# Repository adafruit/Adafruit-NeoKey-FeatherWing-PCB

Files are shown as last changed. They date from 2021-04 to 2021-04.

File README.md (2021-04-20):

## Adafruit NeoKey FeatherWing PCB

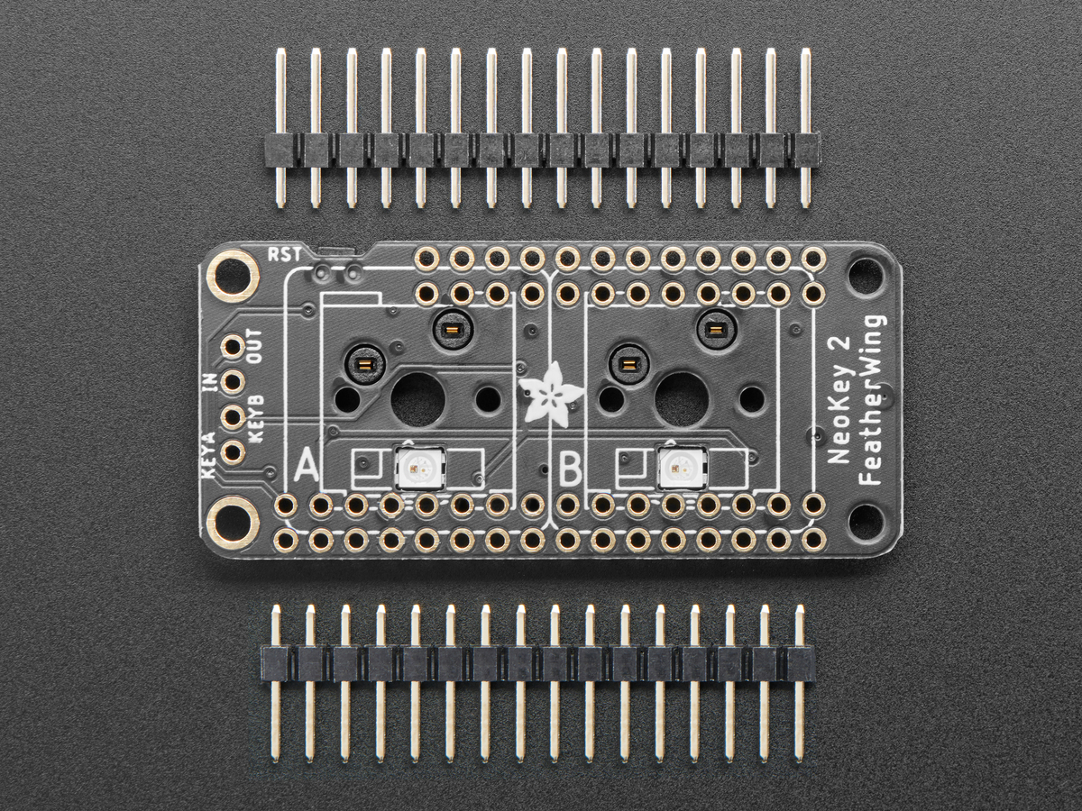
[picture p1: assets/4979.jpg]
<a href="http://www.adafruit.com/products/4979"><br/>
Click here to purchase one from the Adafruit shop</a>

PCB files for the Adafruit NeoKey FeatherWing. 

Format is EagleCAD schematic and board layout
* https://www.adafruit.com/product/4979

### Description

The only thing better than a nice mechanical key, is two of them, and ones that also can glow any color of the rainbow - and that's what the Adafruit NeoKey FeatherWing will let you do! This Wing plugs into any/all Feather main boards and can fit two Cherry MX or compatible switches to turn your Feather into the lil'est macro keypad.

Each Wing has two Kailh sockets, which means you can plug in any MX-compatible switches instead of soldering them in. You may need a little glue to keep the switches in place: hot glue or a dot of epoxy worked fine for us.

Beneath each switch is a reverse-mount NeoPixel pointing up through the spot where many switches would have an LED to shine though. The two pixels are chained together so you can control them as one 2-pixel NeoPixel strand.

We wired the switches up very simply, so you can use with any Feather. There's jumper pads you can cut to re-wire the switches and LED strand.

* Switch A - Connects to the Feather pin to the left of SCL, on most Feathers this is pin D5
* Switch B - Connects to the Feather pin two pins to the left of SCL, on most Feathers this is pin D6
* NeoPixel Input - Connects to the Feather pin three pins to the left of SCL, on most Feathers this is pin D9
* Bonus STEMMA QT connector allows you to make solderless connections between your Wing and a wide range of other sensors and accessories using a compatible cable. QT Cable is not included, but we have a variety in the shop.

Please note, each order comes with one assembled FeatherWing PCB and a two sticks of break-off header. Soldering is required to attach the header and connect to a Feather. Two mechanical switches and key caps are not included! Use any MX-compatible switch: Kailh, Gateron, etc all work.
### License

Adafruit invests time and resources providing this open source design, please support Adafruit and open-source hardware by purchasing products from [Adafruit](https://www.adafruit.com)!

Designed by Limor Fried/Ladyada for Adafruit Industries.

Creative Commons Attribution/Share-Alike, all text above must be included in any redistribution. 
See license.txt for additional details.

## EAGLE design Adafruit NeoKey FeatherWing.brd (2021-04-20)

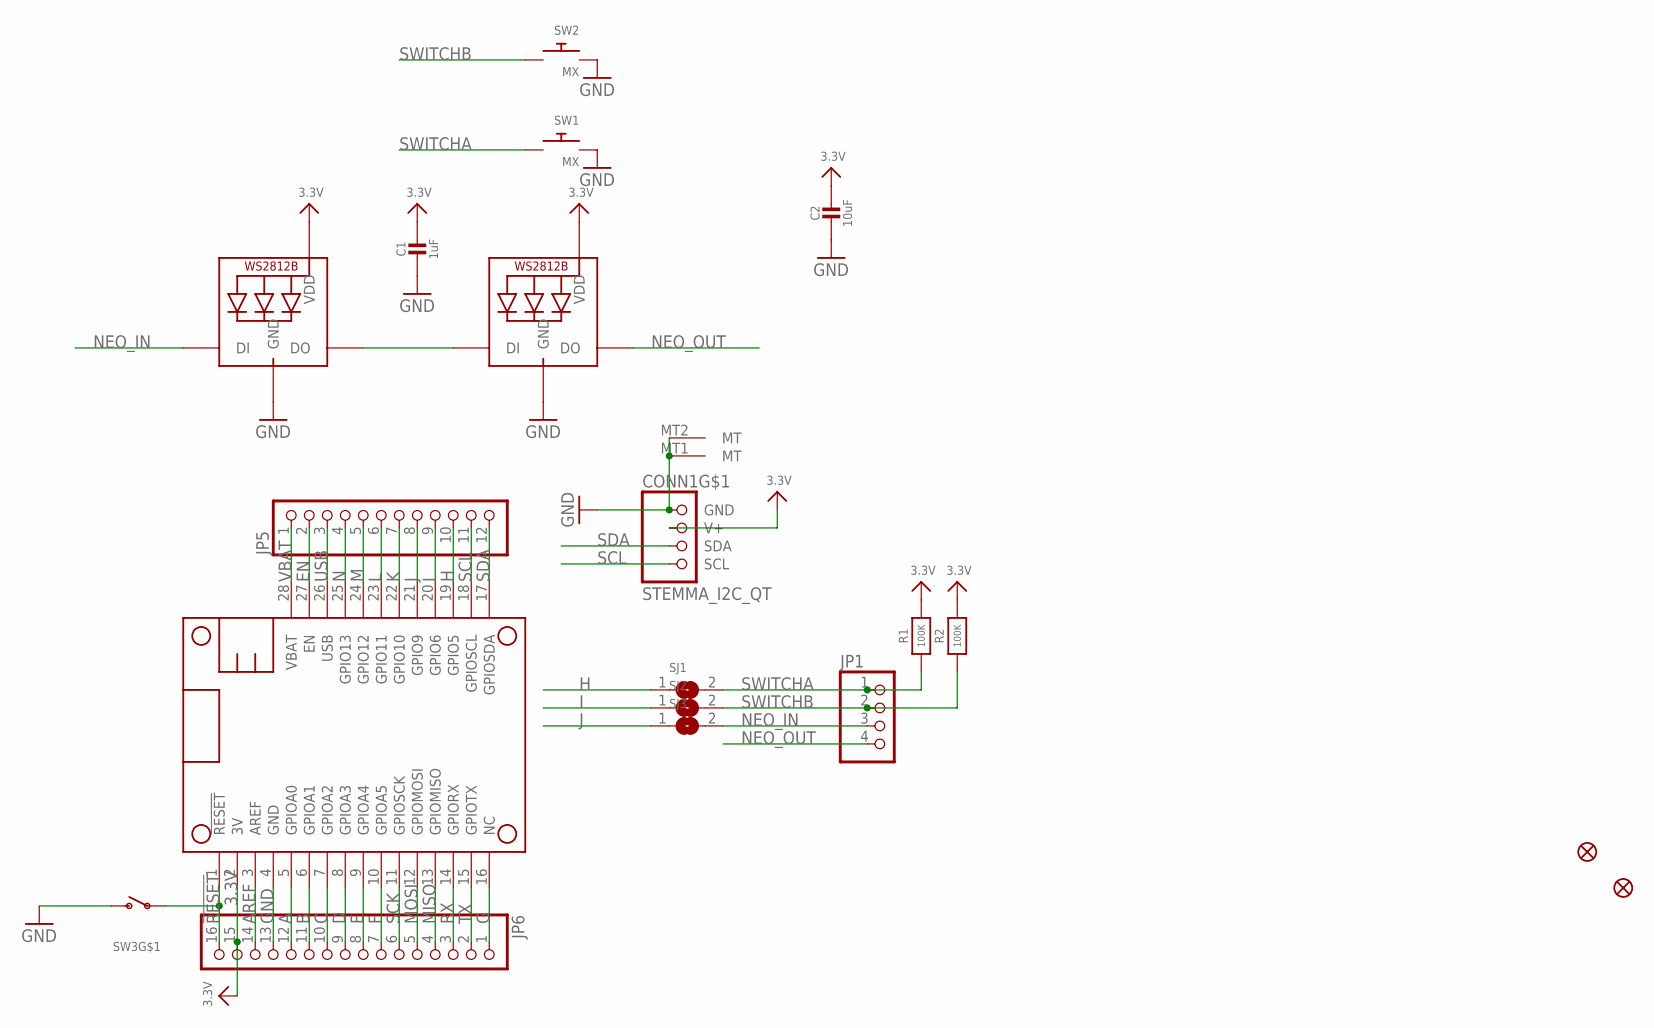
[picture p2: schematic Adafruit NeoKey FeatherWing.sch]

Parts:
C1: 1uF; 0603-NO
C2: 10uF; 0805-NO
CONN1: STEMMA_I2C_QT; JST_SH4
FID1, FID2: FIDUCIAL_1MM
JP1: HEADER-1X4ROUND; 1X04_ROUND
JP5: HEADER-1X12; 1X12_ROUND
JP6: HEADER-1X16ROUND; 1X16_ROUND
LED1, LED2: WS2812B_SK6812E; NEO3535_REVERSE
MS1: FEATHERWING_NODIM
R1, R2: 100K; 0603-NO
SJ1, SJ2, SJ3: SOLDERJUMPERCLOSED; SOLDERJUMPER_CLOSEDWIRE
SW1, SW2: MX; KAILH_SOCKET
SW3: SWITCH_SPST_TACT_RA; SPST_TACTILE_RA

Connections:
3.3V: C1.1, C2.1, CONN1.2 (V+), JP6.15, LED1.1-VDD (VDD), LED2.1-VDD (VDD), MS1.2 (3V), R1.2, R2.2
!RESET: JP6.16, MS1.1 (!RESET), SW3.1
A: JP6.12, MS1.5 (GPIOA0)
AREF: JP6.14, MS1.3 (AREF)
B: JP6.11, MS1.6 (GPIOA1)
C: JP6.10, MS1.7 (GPIOA2)
D: JP6.9, MS1.8 (GPIOA3)
E: JP6.8, MS1.9 (GPIOA4)
EN: JP5.2, MS1.27 (EN)
F: JP6.7, MS1.10 (GPIOA5)
G: JP6.1, MS1.16 (NC)
GND: C1.2, C2.2, CONN1.1 (GND), CONN1.MT1 (MT), CONN1.MT2 (MT), JP6.13, LED1.3-GND (GND), LED2.3-GND (GND), MS1.4 (GND), SW1.1, SW2.1, SW3.2 (S)
H: JP5.10, MS1.19 (GPIO5), SJ1.1
I: JP5.9, MS1.20 (GPIO6), SJ2.1
J: JP5.8, MS1.21 (GPIO9), SJ3.1
K: JP5.7, MS1.22 (GPIO10)
L: JP5.6, MS1.23 (GPIO11)
M: JP5.5, MS1.24 (GPIO12)
MISO: JP6.4, MS1.13 (GPIOMISO)
MOSI: JP6.5, MS1.12 (GPIOMOSI)
N: JP5.4, MS1.25 (GPIO13)
unnamed: LED1.4-DIN (DI), LED2.2-DOUT (DO)
NEO_IN: JP1.3, LED2.4-DIN (DI), SJ3.2
NEO_OUT: JP1.4, LED1.2-DOUT (DO)
RX: JP6.3, MS1.14 (GPIORX)
SCK: JP6.6, MS1.11 (GPIOSCK)
SCL: CONN1.4 (SCL), JP5.11, MS1.18 (GPIOSCL)
SDA: CONN1.3 (SDA), JP5.12, MS1.17 (GPIOSDA)
SWITCHA: JP1.1, R1.1, SJ1.2, SW1.2
SWITCHB: JP1.2, R2.1, SJ2.2, SW2.2
TX: JP6.2, MS1.15 (GPIOTX)
USB: JP5.3, MS1.26 (USB)
VBAT: JP5.1, MS1.28 (VBAT)

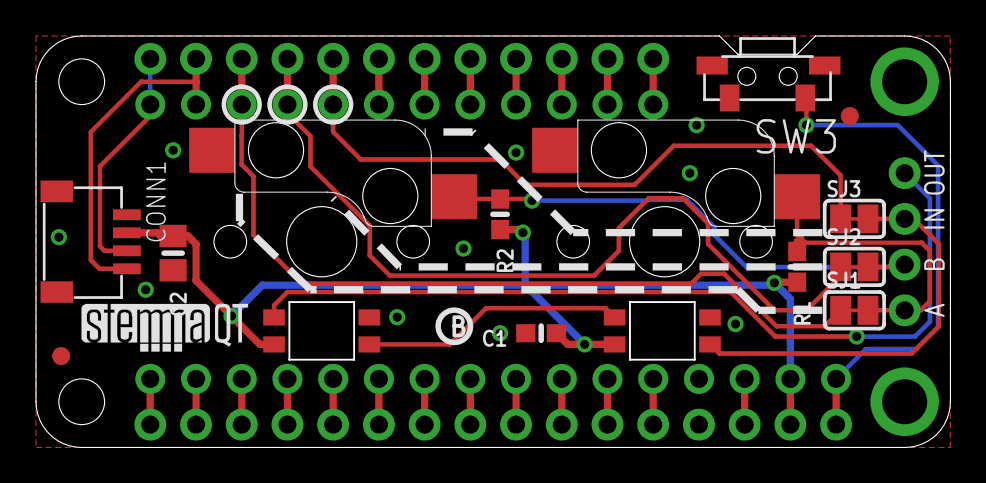
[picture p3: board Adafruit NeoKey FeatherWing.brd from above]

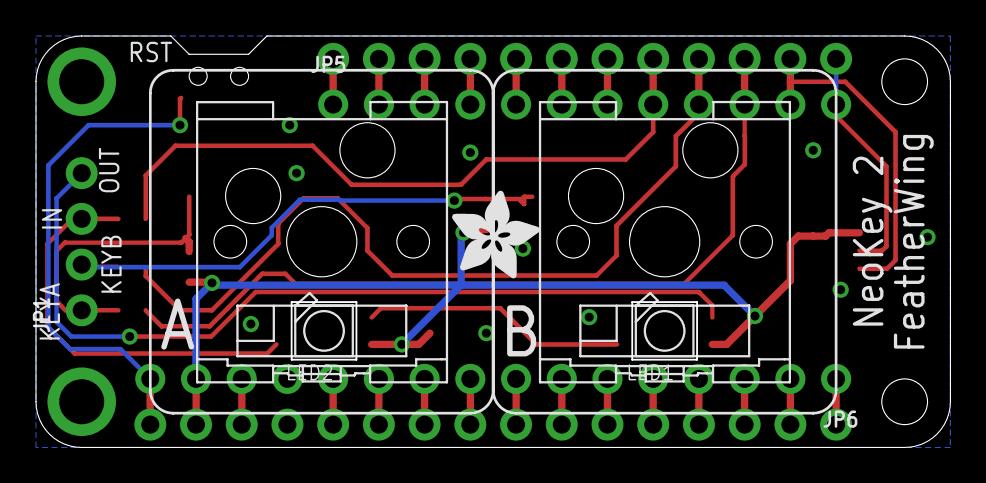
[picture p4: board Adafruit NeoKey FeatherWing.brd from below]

Board: 2 copper layers, 50.8 x 22.9 mm, 22 parts (9 on the bottom side), 33 nets.

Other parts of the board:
U$7: ADAFRUIT_5MM
U$8: PCBFEAT-REV-040
U$11: STEMMAQT

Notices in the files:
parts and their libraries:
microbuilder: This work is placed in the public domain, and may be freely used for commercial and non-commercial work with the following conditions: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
